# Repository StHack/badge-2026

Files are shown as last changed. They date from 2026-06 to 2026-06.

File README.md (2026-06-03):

# Badge Sthack 2026

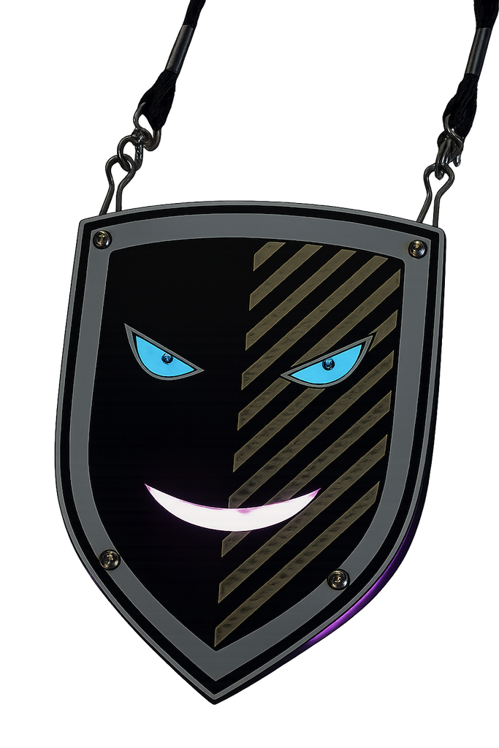
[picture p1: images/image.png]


This electronic badge was designed for [Sthack 2026](https://sthack.fr) and given to every participant at the beginning of the CTF on May 29th, 2026.

| [User manual](firmware/README.md) | [Hardware](hardware/README.md) |
| --- | --- |

---

## Story

The badge was handed to you at the beginning of the CTF, eyes closed, lost in a paradoxical sleep, patiently waiting for the morning to wake up. But the night is long, and full of dreams and nightmares.

**Can you comfort it?**

---

## First boot

The badge starts in **sleep mode**. After powering on (confirmed by a beep), nothing happens. Its eyes are closed.

If you press a button, its eyes open for a brief moment, it sees you, then fall back shut. Nothing else. He's sleeping.

---

## Nightmares

During its sleep, the badge wakes up randomly every **5 to 15 minutes**. When a nightmare strikes:

- Its eyes turn sick and blurry
- It lets out its unique cry
- Its LEDs pulse red

**You have 20 seconds to react.**

Press any button to launch a minigame. Win the game to level up the badge: heart eyes, pink LEDs, a victory jingle, and the level number scrolled across the displays.

Miss the window and the nightmare passes without consequence, it will try again later.

**Reach level 10 to unlock the CTF flag.**

### Minigames

| Level | Game | How to play | Score required |
| ----- | --- | --- | --- |
| 1 | **Stop** | Stop the cursor inside the zone | 3 rounds |
| 2 | **Dino** | Jump over obstacles | 5 obstacles |
| 3 | **Maze** | LEFT/RIGHT to rotate, CENTER to move forward | Reach the exit |
| 4 | **Pac-Man** | Eat dots, avoid ghosts | 20 points |
| 5 | **Snake** | LEFT/RIGHT, eat food without hitting borders or yourself | 10 points |
| 6 | **Tetris** | Clear horizontal lines | 8 lines |
| 7 | **Breakout** | Destroy all bricks (5 lives) | Clear all bricks |
| 8 | **Simon** | Memorise and repeat the button sequence | 8 rounds |
| 9 | **Flappy Bird** | CENTER to flap through the pipes | 10 points |
| 10 | **Mastermind**  | Deduce the hidden sequence | Find the code |

---

## Wake-up

At the end of the night, a wake signal was broadcast to wake all badges simultaneously. Every badge that was still present opened its eyes, lit up its LEDs, played its unique melody.

From that point on, the badge is fully awake: eyes animated at all times, full menu accessible, all minigames unlocked, and customisation available.

Badges that had left the event before the signal remained asleep.

---

## Badge identity

Each badge has its own unique name, cry, and melody.

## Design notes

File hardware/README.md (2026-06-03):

# Hardware

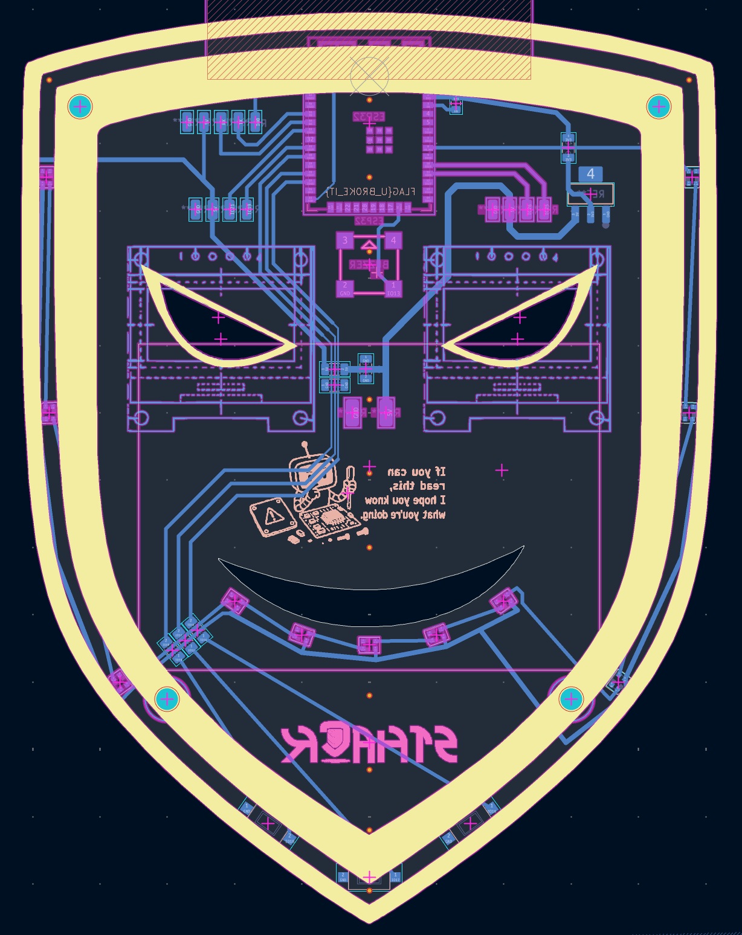
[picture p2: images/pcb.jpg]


## Overview

The entire design, fabrication, assembly, and programming of 200 badges was completed in one month as a side project. With no time to run test batches before the final production run, every decision had to be right the first time. This shaped the approach: minimize risk by keeping the design simple and well-understood, rather than pushing boundaries that could not be validated in time.

---

## PCB

The [KiCad project](pcb/) is a two-layer SMD board shaped like the Sthack shield. All components are mounted on the back. The two OLED displays are soldered using U-shaped pin headers, keeping the front surface completely clean with no visible holes. This was a deliberate aesthetic choice.

---

## 3D printed plate

A 3D printed plate screws onto the back of the PCB and is shaped to fit around the components. It houses several integrated features:

- Small tunnels run behind the mouth LED strip to diffuse the light more evenly across the front.
- Two sliding brackets hold the AA battery box in place.
- A stop piece prevents the battery box from being pulled out too easily.
- The lanyard hooks are sandwiched between the plate and the PCB, held in place by the assembly itself without additional fasteners.

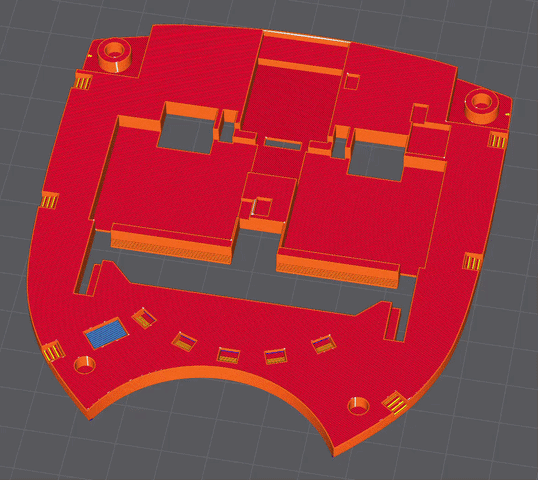
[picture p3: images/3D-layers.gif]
3D layers


---

## Assembly process

### Screen soldering

A printed support and a plate hold both OLED displays at the correct height and angle during soldering, ensuring perfect alignment on every badge.

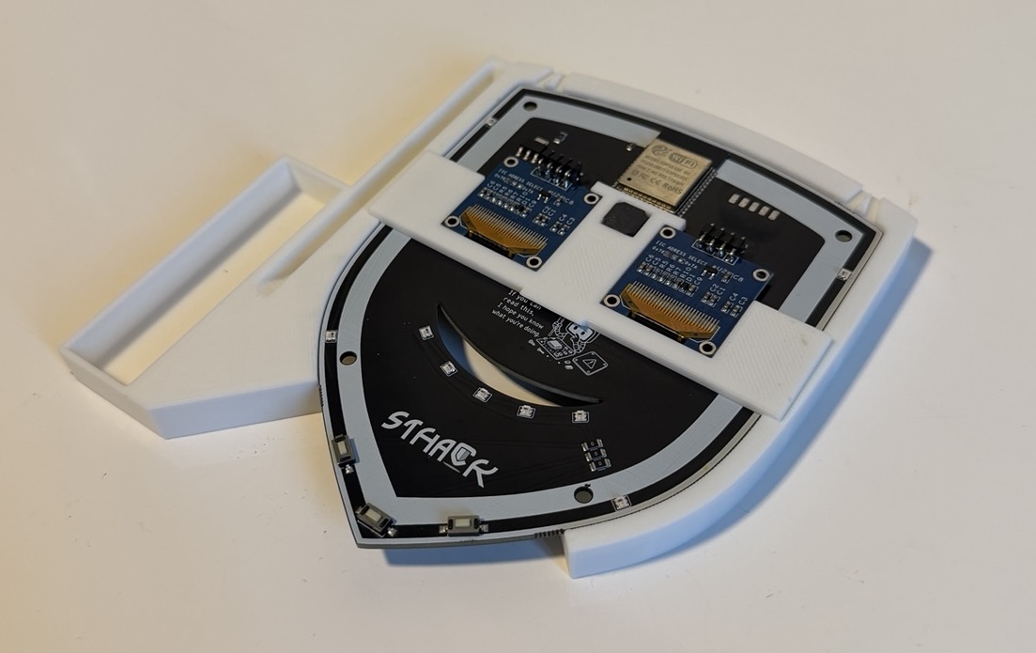
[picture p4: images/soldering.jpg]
Screen soldering


Files are in [`3D/soldering/`](3D/soldering/).

### Programming

Each PCB is placed into a custom-made programming dock that holds the badge at a fixed position, aligning a set of pogo pins with the programming pads on the board. This allows flashing the firmware without soldering any connector.

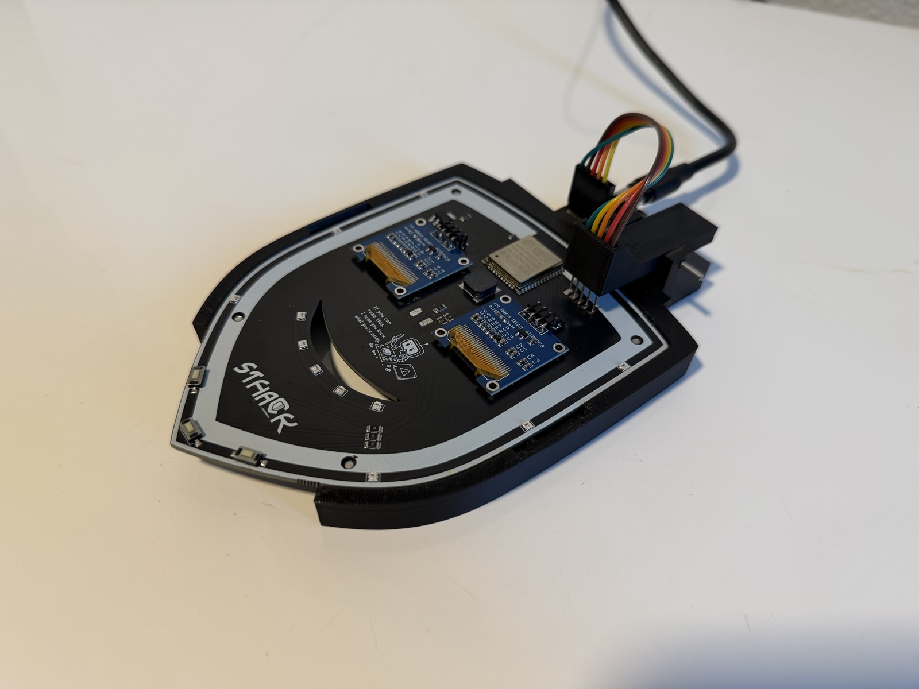
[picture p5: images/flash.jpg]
Programming


The dock is 3D printed. Files are in [`3D/programming/`](3D/programming/).

To speed up flashing 200 badges, a batch script ([`firmware/flash_batch.py`](../firmware/flash_batch.py)) flashes multiple badges in parallel across several USB ports. An audio feedback system plays distinct sounds to signal when a flash succeeds or fails, so there is no need to watch the screen between each badge.

### Brass thread inserts

The 3D plate uses heat-set brass inserts for the screw holes. A jig positions the plate precisely under the soldering iron tip to make insertion consistent.

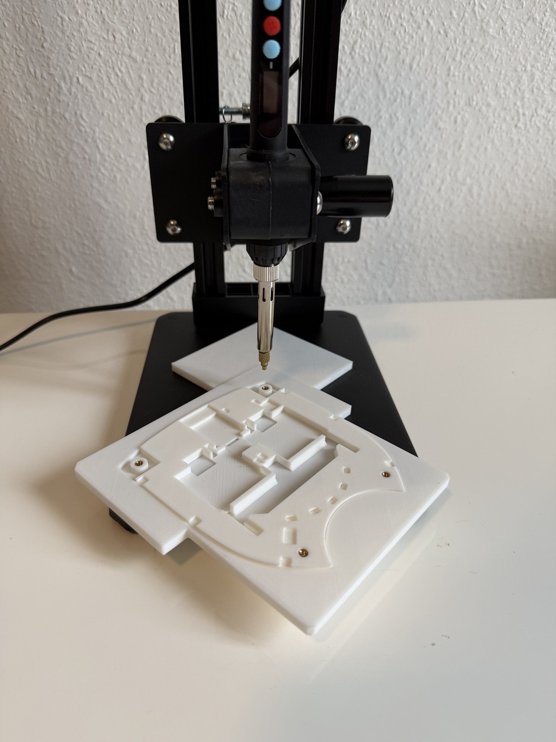
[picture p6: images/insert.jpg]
Thread inserts


Files are in [`3D/threads/`](3D/threads/).

### Final assembly

Components are positioned on the plate, the battery box wires are soldered to the PCB, and everything is secured with 4 screws, also holding necklace.

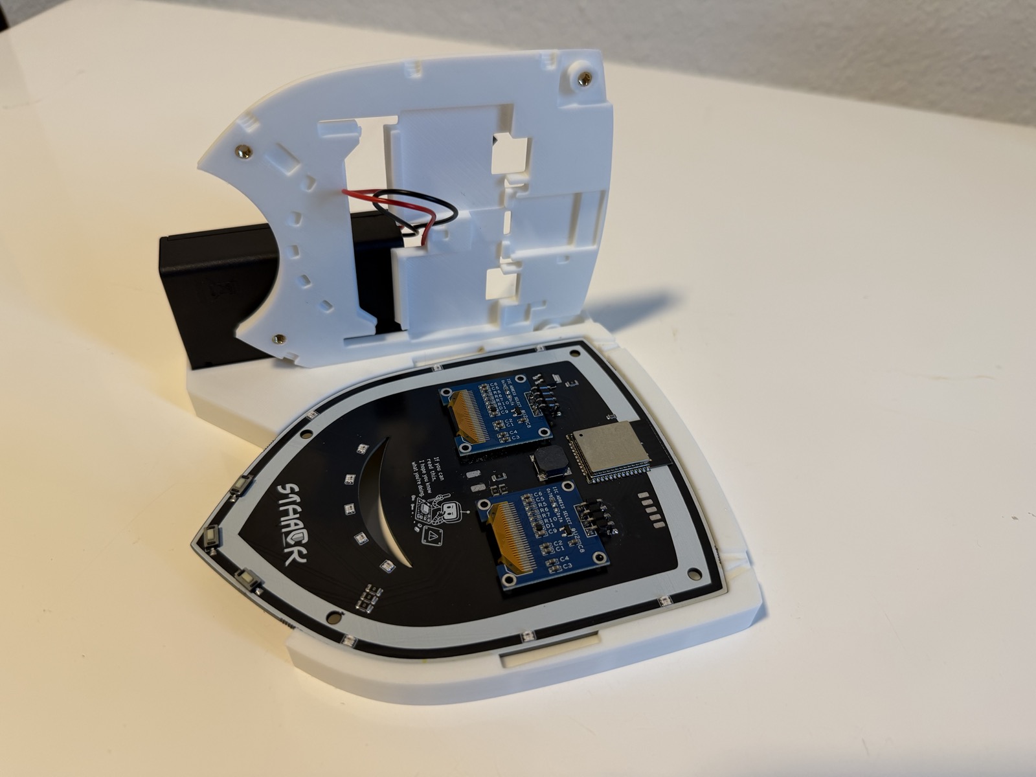
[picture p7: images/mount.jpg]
Final assembly


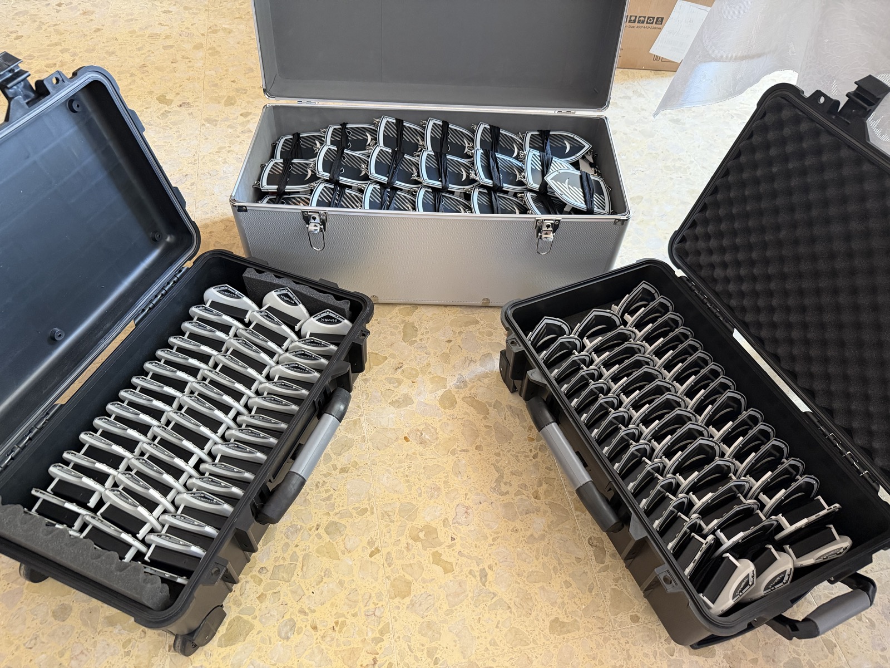
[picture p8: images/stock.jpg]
200 finished badges


---

## Bill of materials

| Component | Reference | Details |
| --- | --- | --- |
| SoC | [ESP32-WROOM-32E](components-datasheets/C19949066.pdf) | 240 MHz, 4 MB Flash, 520 KB SRAM, BLE + WiFi |
| Display | [SSD1306](components-datasheets/SSD1306.jpeg) x 2 | 128x64 OLED, I2C @ 0x3C |
| LEDs | [WS2812B](components-datasheets/C965555.pdf) x 11 | 3 left ring + 5 mouth + 3 right ring, single GPIO data line |
| Buttons | SMD push x 3 | Active-low, internal pull-up, Left / Center / Right |
| Buzzer | [Passive piezo](components-datasheets/C7544813.pdf) | PWM via LEDC, ~2500 Hz resonance |
| Regulator | [AMS1117-3.3](components-datasheets/C6186.pdf) | 3.3 V LDO regulator for the ESP32 |
| Resistors | [0402](components-datasheets/C17888.pdf) | Pull-up / current-limiting resistors |

---

## Pin assignments

| Signal | GPIO |
| --- | ---- |
| Left display SDA  | 19 |
| Left display SCL  | 21 |
| Right display SDA | 25 |
| Right display SCL | 26 |
| WS2812B data | 32 |
| Button LEFT | 18 |
| Button CENTER | 17 |
| Button RIGHT | 16 |
| Buzzer PWM | 13 |

---

## LED segments

The 11 LEDs are wired in a single chain on GPIO 32:

```
Index  0  1  2        Left ring  (3 LEDs)
Index  3  4  5  6  7  Mouth strip (5 LEDs)
Index  8  9  10       Right ring (3 LEDs)
```

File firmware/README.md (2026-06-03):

# User Guide

## Menu

Hold **CENTER** for 0.5 s in awake mode to open the menu.

```
Menu
├── Info
│   ├── Name
│   ├── ID
│   └── Version
├── Games
│   └── [Games list]
├── Skin
│   ├── Eyes
│   ├── Mouth
│   ├── Rings
│   └── Blink
├── Settings
│   ├── LEDs
│   ├── Sound
│   └── Bluetooth
│       ├── Server
│       └── Remote control
└── Bonus
```

- **Navigate:** LEFT / RIGHT to browse entries
- **Confirm:** CENTER (short press)
- **Back / exit:** hold CENTER

### Info

Displays your badge's identity:

- **Name:** your badge's unique name (plays its unique cry when clicked)
- **ID:** its 6-character identifier
- **Version:** firmware version

### Games

Play any game freely, without waiting for a nightmare. The first 10 are part of the tamagotchi progression.

| Game | How to play |
| --- | --- |
| **Simon** | Memorise and repeat the button sequence |
| **Stop** | Stop the cursor inside the zone |
| **Snake** | Eat food without hitting borders or yourself |
| **Mastermind**  | Deduce the hidden sequence |
| **Tetris** | Clear horizontal lines |
| **Flappy Bird** | CENTER to flap through the pipes |
| **Breakout** | Destroy all bricks without letting the ball fall |
| **Pac-Man** | Eat dots, avoid ghosts |
| **Doodle Jump** | Keep jumping upward without falling |
| **Maze** | LEFT/RIGHT to rotate, CENTER to move forward |
| **Dino** | Jump over obstacles |
| **Space Inv.**  | Shoot down waves of descending aliens |

### Skin

Customise the visual appearance of your badge.

| Option | Available styles |
| --- | --- |
| **Eyes**  | Standard, Hearts, Stars, Matrix, Hypnosis, Bolt, Reptile, Infinity, Anime, Scope, Clock, Robot, Lock, Wifi, Cat, Human |
| **Mouth** | Off, Pink, Rainbow, Lava, Chill, Candle, Cyber, VU, Bounce, Sparkle, Ocean, Toxic, Aurora, Heartbeat, Matrix |
| **Rings** | Off, BluePulse, CyanPulse, Rainbow, Fire, Police, Comet, Breathing, Disco, Strobe, GreenPulse, Aurora, Sunset, Thunder, Heartbeat |
| **Blink** | ON / OFF : enable or disable automatic eye blinking |

### Settings

| Setting | What it does |
| --- | --- |
| **LEDs** | Overall LED brightness, from 0 (off) to 10 (maximum) |
| **Sound** | Mute or unmute the buzzer (ON / OFF) |
| **Bluetooth** | Submenu for wireless connection options |
| &emsp;Server | Enable the GATT server to accept Bluetooth connections  |
| &emsp;Remote control | Allow the badge to receive remote BLE commands |

---

## Bluetooth interface

When the GATT server is enabled (Settings > Bluetooth > Server), the badge can be controlled from a browser using the [`badge.html`](badge.html) page.

Open the file locally in Chrome or Edge (Web Bluetooth is not supported in other browsers), click **Connect**, and select your badge from the device list. A PIN is displayed on the badge for a few seconds to confirm the pairing.

During the event, a BLE broadcast system was used to send commands to all badges simultaneously. This can be disabled in Settings > Bluetooth > Remote control. See [`BLUETOOTH.md`](BLUETOOTH.md) for details.

---

## Power

In sleep mode the badge wakes every 30 seconds, scans BLE beacons for 2 seconds, then goes back to sleep. This keeps average current around **17 mA**, giving a comfortable runtime on 3 AA batteries across a full night event. When fully awake (displays on, LEDs animating), consumption rises to around **150 mA**.

---

## Development

### Build

The firmware uses [PlatformIO](https://platformio.org/). From the `firmware/` directory:

```bash
pio run
```

The compiled binary is written to `.pio/build/esp32dev/firmware.bin`.

### Flash over Bluetooth

1. Enable the GATT server on the badge (Settings > Bluetooth > Server).
2. Open `tools/badge.html` in Chrome or Edge and connect to the badge.
3. In the OTA section, drag and drop `firmware.bin` onto the upload area and confirm.

The badge reboots automatically once the transfer is complete.

### Flash via USB

Connect the badge to USB and run:

```bash
pio run --target upload
```

For serial output:

```bash
pio device monitor
```

### Rollback

The flash is split into two OTA slots (see [`partitions_badge.csv`](partitions_badge.csv)):

```
app0  ota_0  0x010000  ~1.97 MB
app1  ota_1  0x200000  ~1.97 MB
```

Each OTA update writes to the inactive slot and switches the boot pointer to it. The previously running firmware stays intact in the other slot.

To roll back to the previous firmware, hold **LEFT + CENTER + RIGHT** while powering on the badge. The bootloader switches the active slot back and reboots into the older firmware.

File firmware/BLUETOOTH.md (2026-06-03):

# Bluetooth signals

Two independent BLE mechanisms coexist: **beacon broadcast** (one-way, no pairing) and **GATT server** (bidirectional, requires pairing).

---

## Beacon format

Signals are broadcast as BLE advertisements with manufacturer-specific data in plain ASCII:

```
ST:<COMMAND>[:<BADGE_ID>][|<PAYLOAD>][~P][~B]
```

| Field | Description |
|---|---|
| `ST:` | Fixed prefix, identifies a Sthack badge signal |
| `<COMMAND>` | Command name (see table below) |
| `:<BADGE_ID>` | Optional, 6-char uppercase hex (last 3 bytes of MAC). If absent, signal applies to all badges |
| `\|<PAYLOAD>` | Optional command-specific data |
| `~P` | Proximity flag, badge ignores this signal if RSSI < -65 dBm |
| `~B` | Boot flag, only processed during the targeted boot scan (hold CENTER at power-on) |

Flags can be combined: `ST:WAKE:A3F201~P~B`

---

## Beacon commands

| Command | Full format | Effect |
|---|---|---|
| `WAKE` | `ST:WAKE[:<ID>]` | Switch badge to **FullMode** (eyes open, menu accessible) |
| `SLEEP` | `ST:SLEEP[:<ID>]` | Return badge to **SleepMode** |
| `BG_ON` | `ST:BG_ON[:<ID>]` | Badge stays awake and scans continuously, ignores sleep timer |
| `BG_OFF` | `ST:BG_OFF[:<ID>]` | Resume normal sleep cycle |
| `CRY` | `ST:CRY[:<ID>]` | Play the badge's unique Pokemon-style cry |
| `MSG` | `ST:MSG[:<ID>]\|<text>` | Cry + scroll text across both displays |
| `OTA` | `ST:OTA[:<ID>]\|<version>` | Connect to the hardcoded WiFi AP and update firmware if badge version < target |
| `TAMA` | `ST:TAMA[:<ID>]` | Force-trigger a tamagotchi interaction immediately |
| `CLEAR` | `ST:CLEAR[:<ID>]` | Reset dedup state, allows re-sending the last command |

### Examples

```
ST:WAKE                        # wake all badges
ST:WAKE:A3F201                 # wake only badge A3F201
ST:MSG|Welcome to Sthack!      # broadcast message to all
ST:MSG:A3F201|Good luck        # targeted message
ST:OTA|0.6                     # OTA update if badge is older than 0.6
ST:TAMA~P                      # trigger tama only for nearby badges (RSSI >= -65 dBm)
ST:WAKE~B                      # only processed during targeted boot scan
```

---

## Deduplication

The badge ignores repeated identical beacons to avoid acting on the same signal multiple times during a scan window. Send `ST:CLEAR` (or `ST:CLEAR:<ID>`) to reset this state before re-sending a command.

---

## GATT server

The GATT server is started from **Settings > Bluetooth** in FullMode. It requires a PIN confirmation on the badge before accepting commands (4-digit PIN displayed on screen, enter via buttons).

**Service UUID:** `19b10020-e8f2-537e-4f6c-d104768a1214`

| Characteristic | UUID | Access | Purpose |
|---|---|---|---|
| Info | `19b10021-...` | Read | Badge ID, name, firmware version |
| Command | `19b10023-...` | Write | Control commands (see below) |
| Music | `19b10024-...` | Write | Play RTTTL melody |
| PIN | `19b10025-...` | Write | Submit PIN for authentication |
| OTA data | `19b10027-...` | Write | BLE OTA firmware transfer (244-byte chunks) |

### GATT command strings (write to `19b10023`)

| Command | Effect |
|---|---|
| `EYE:<N>` | Set eye animation (0=FSM, 1=closed, 2=awake, 3=sleepy, 4=hearts, 5=scroll, 6=blinking, 7=calm) |
| `LED:<N>` | Set LED animation mode |
| `TEXT:<text>` | Scroll text across both displays |
| `MUSIC:<rtttl>` | Play an RTTTL melody |
| `CRY` | Trigger badge cry |
| `STYLE:<N>` | Set eye style |
| `GAME:<N>` | Launch a minigame (0=Simon, 1=Stop, 2=Snake, 3=Mastermind, 4=Tetris, 5=Flappy, 6=Breakout, 7=Pac-Man, 8=Doodle, 9=Maze) |
| `TAMA_TRIGGER` | Force tamagotchi interaction |
| `NVS_RESET` | Erase all NVS data and reboot (factory reset) |
| `FSM_WAKE` | Switch to FullMode |
| `FSM_SLEEP` | Switch to SleepMode |

---

## Proximity gating (`~P`)

Any beacon can be restricted to nearby badges by appending `~P`. The badge measures the RSSI of the advertisement and ignores it if RSSI < -65 dBm (approximately 1-2 m in open space). Adjust `kProximityRssiThreshold` in `src/ble/ble_types.h` to tune the range.

---

## Boot-time targeted scan (`~B`)

If CENTER is held at power-on, the badge enters a 2-second targeted scan that only reacts to `~B`-flagged beacons. This allows an organiser to send a command to a specific badge without triggering all nearby badges. Normal broadcast beacons are ignored during this window.

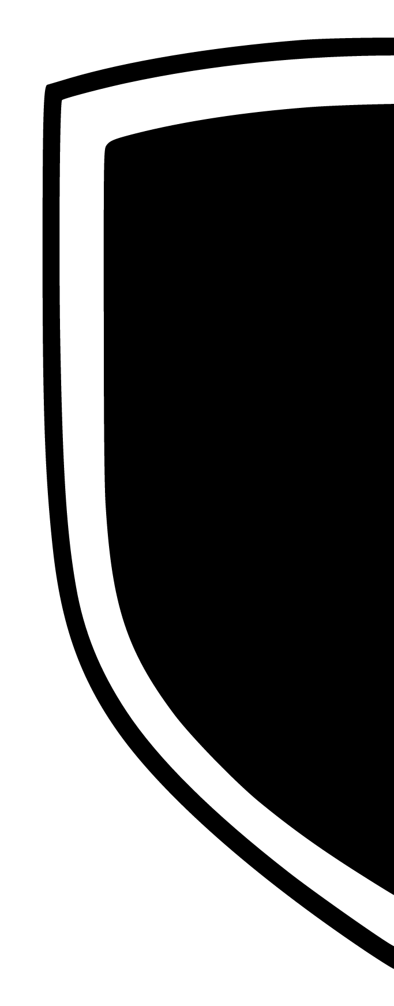
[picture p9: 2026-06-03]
hardware/images/shield/half-shield-left.png

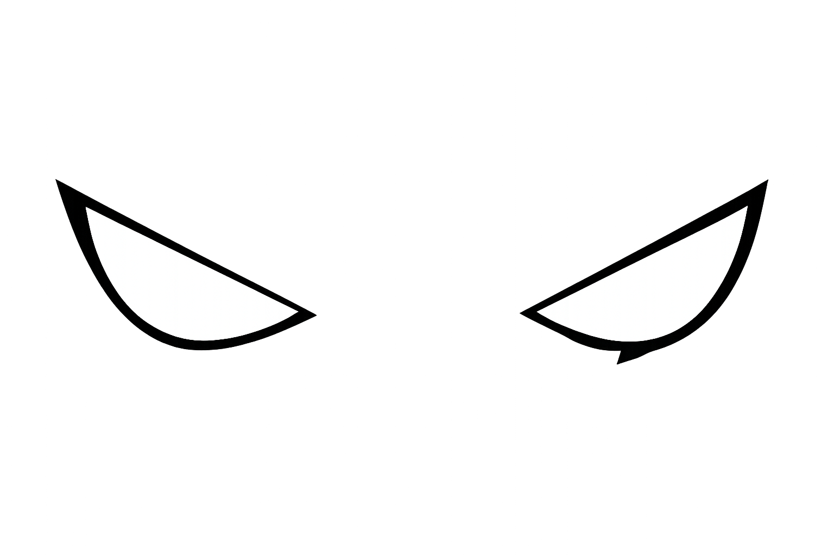
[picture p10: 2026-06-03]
hardware/images/face/eyes-source.png

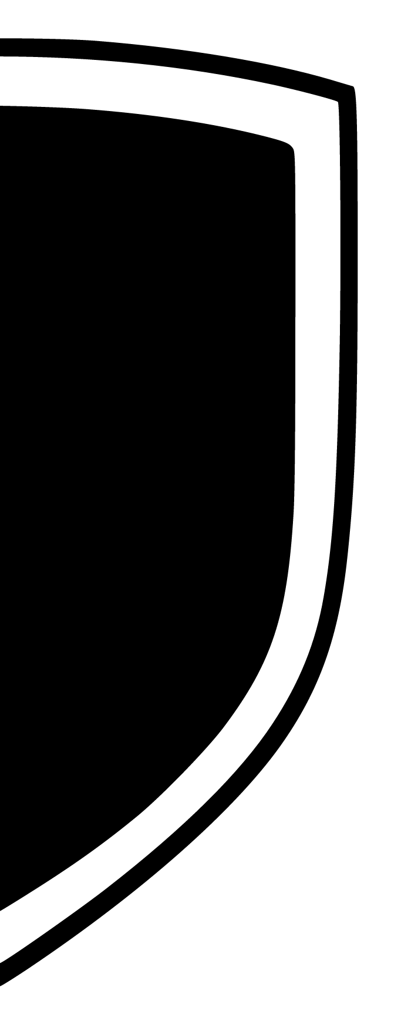
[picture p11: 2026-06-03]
hardware/images/shield/half-shield-right.png

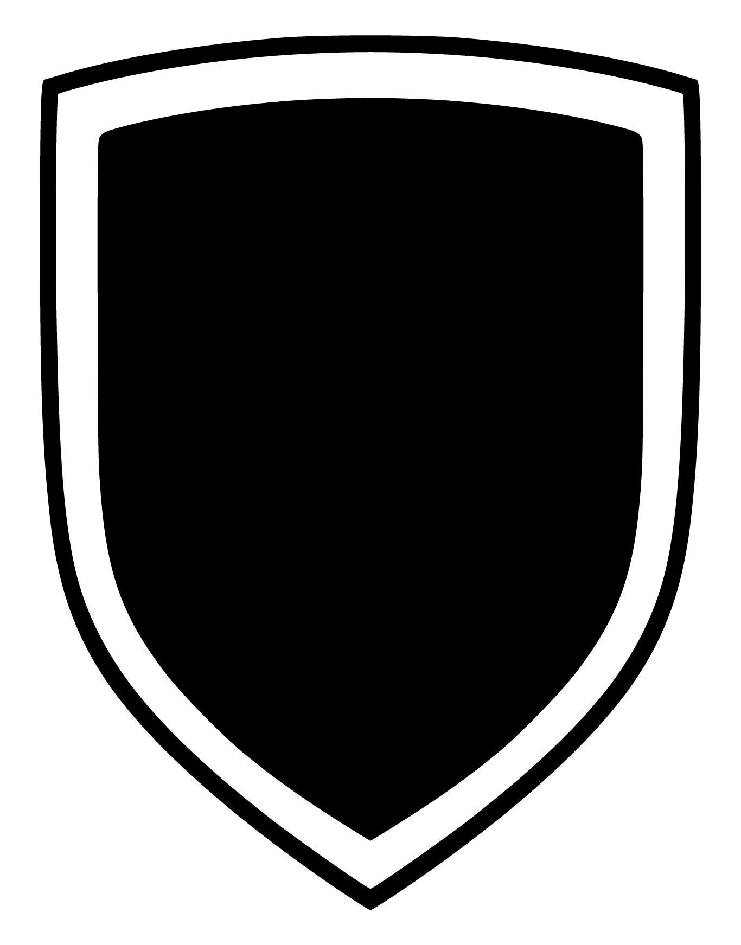
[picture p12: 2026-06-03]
hardware/images/shield/mirror-shield.png

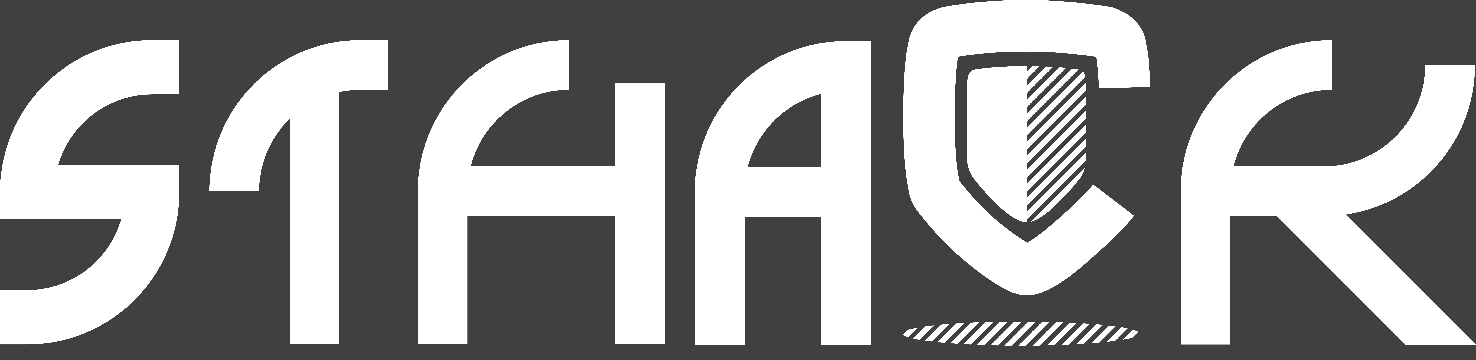
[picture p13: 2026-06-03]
hardware/images/sthack.png

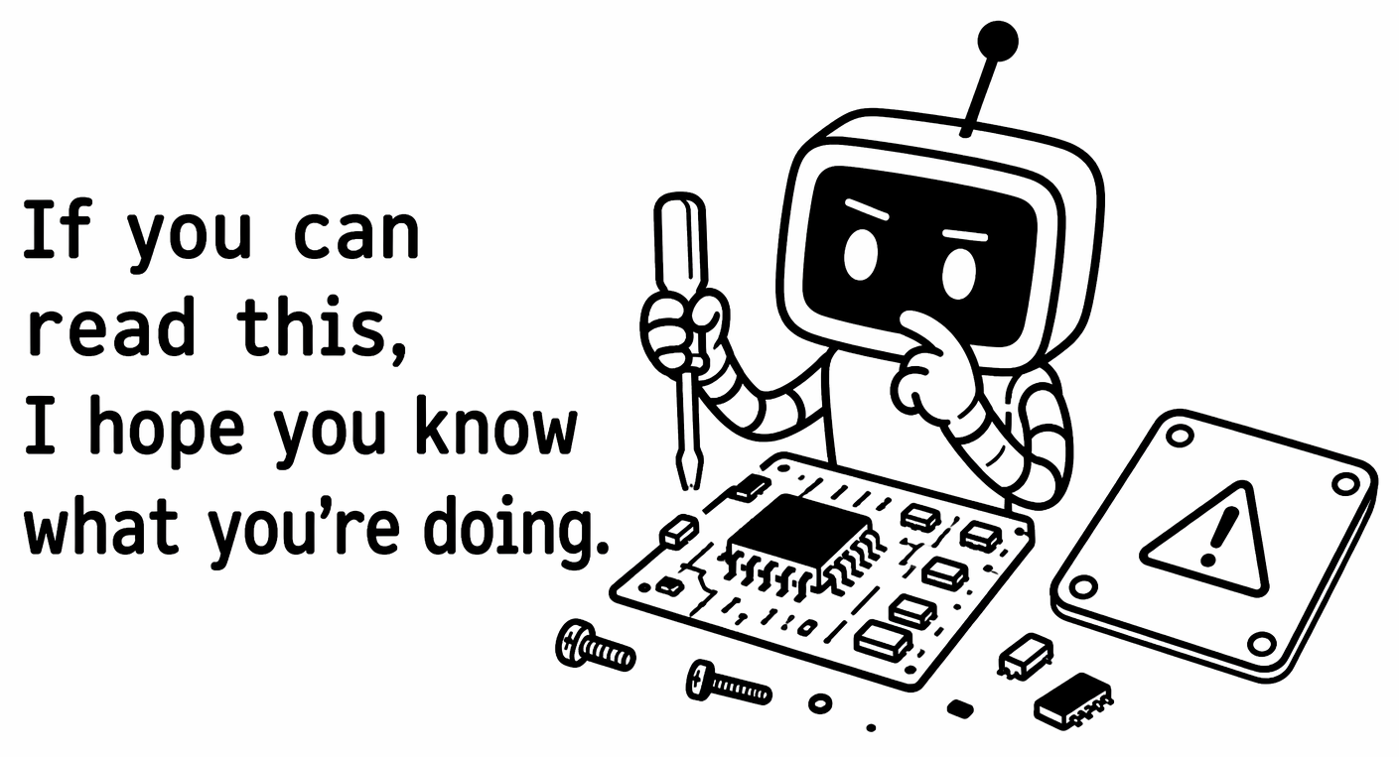
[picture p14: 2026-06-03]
hardware/images/joke.png

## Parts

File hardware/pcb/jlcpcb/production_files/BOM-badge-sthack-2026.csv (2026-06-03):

Comment | Designator | Footprint | LCSC | Quantity
 | BRG | R_1206_3216Metric | C17888 | 1
AMS | AMS | SOT-223-3_L6.5-W3.4-P2.30-LS7.0-BR | C6186 | 1
BUZZER | BUZZER | BUZ-SMD_4P-L8.5-W8.5-P8.50-BR | C7544813 | 1
EN | EN | R_0805_2012Metric | C17414 | 1
ESP32 | ESP32 | ESP32-WROOM-32E | C19949066 | 1
LED_WS2812B-2020_PLCC4_2.0x2.0mm | LED | LED_WS2812B-2020_PLCC4_2.0x2.0mm | C965555 | 1
SW_SPST_CK_RS282G05A3 | BTN | SW_SPST_CK_RS282G05A3 | C2681478 | 1

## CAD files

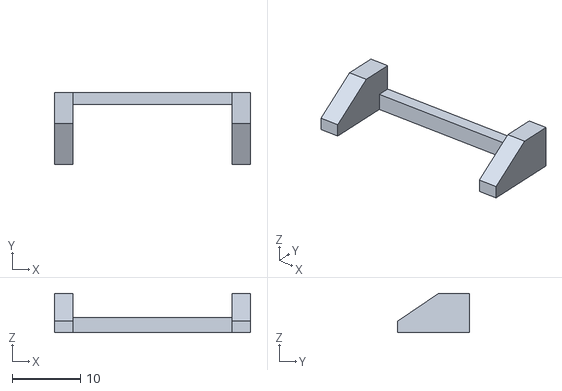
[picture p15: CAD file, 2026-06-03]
hardware/3D/badge/badge-batteries-stop.stl
28.8 x 10.5 x 5.75

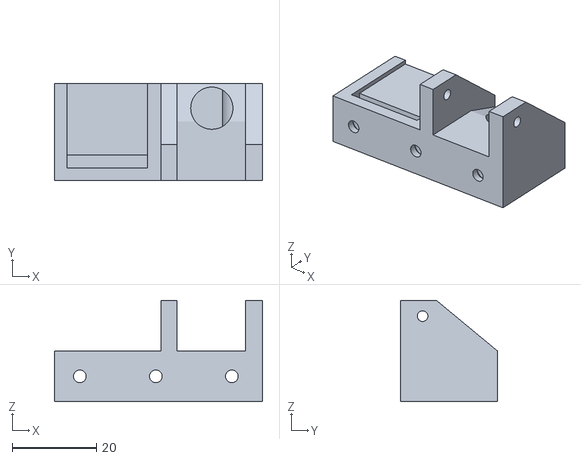
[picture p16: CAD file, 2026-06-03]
hardware/3D/programming/programming-tool-lever-support.stl
49.2 x 23.0 x 24.0

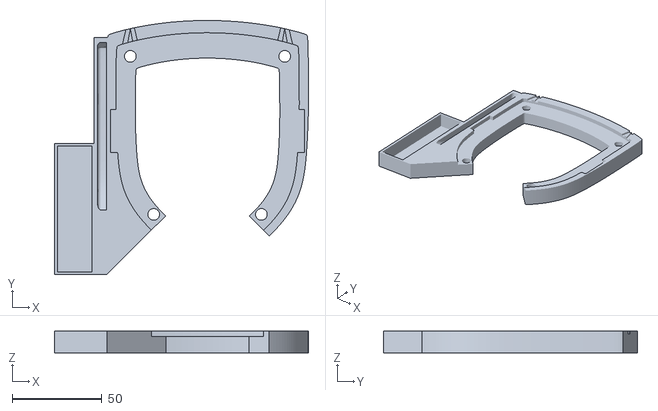
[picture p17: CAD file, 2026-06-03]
hardware/3D/soldering/soldering-support.stl
141.5 x 141.5 x 12.0

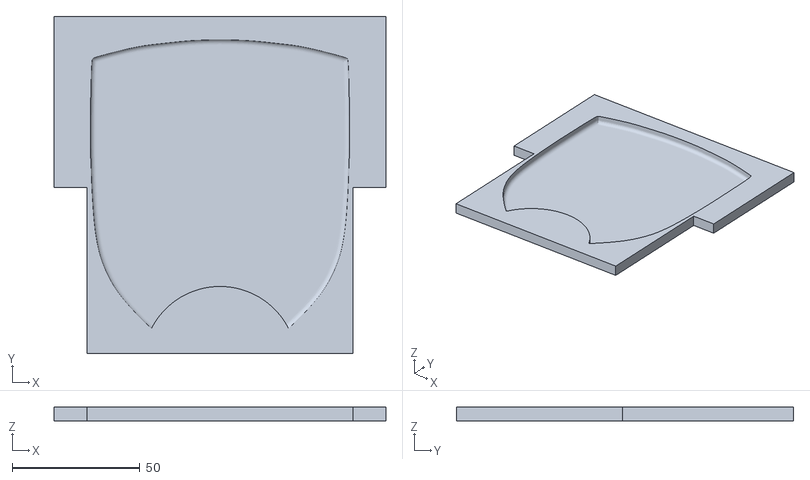
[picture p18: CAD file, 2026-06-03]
hardware/3D/threads/brass-threads-tool-support.stl
130.1 x 132.1 x 5.50

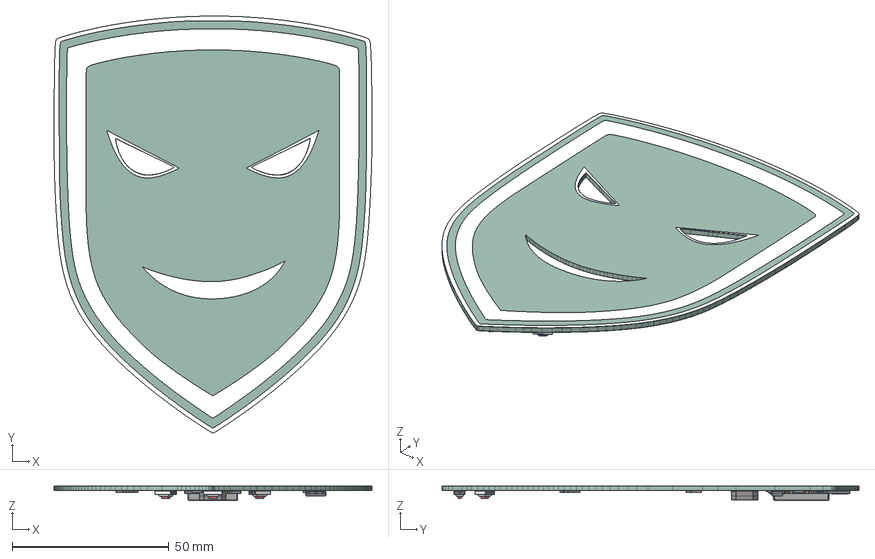
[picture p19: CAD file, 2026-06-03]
hardware/pcb/badge.step
101.6 x 133.2 x 4.77 mm
ESP32-WROOM-32E
R_0805_2012Metric
SOT-223-3_L6.5-W3.4-P2.30-LS7.0-BR
R_1206_3216Metric x 7
SW_SPST_CK_RS282G05A3 x 3
BUZ-SMD_4P-L8.5-W8.5-H3.0
badge-sthack-2026_silkscreen x 2
badge-sthack-2026_PCB

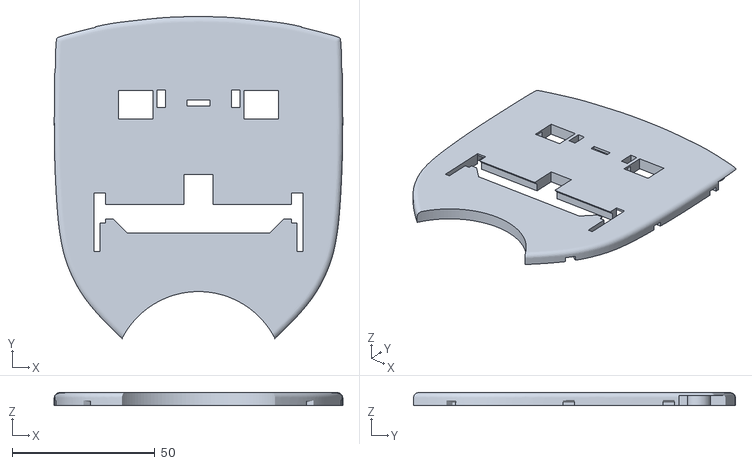
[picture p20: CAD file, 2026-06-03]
hardware/3D/badge/badge-plate.stl
101.0 x 112.7 x 4.50

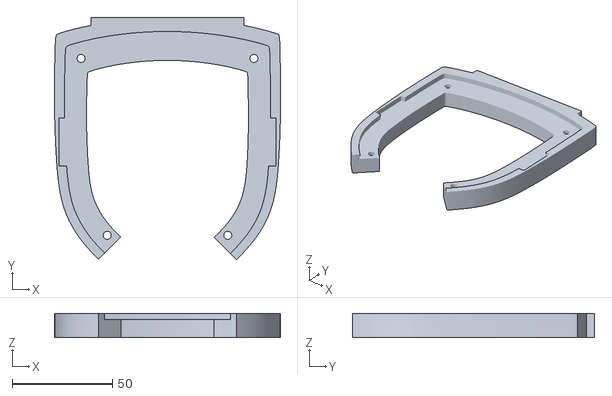
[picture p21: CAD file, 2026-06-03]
hardware/3D/programming/programming-tool.stl
112.5 x 120.6 x 12.0

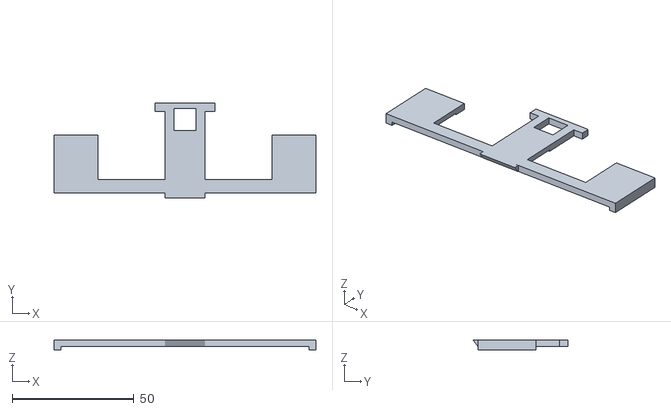
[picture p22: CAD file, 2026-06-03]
hardware/3D/soldering/soldering-screens-support.stl
107.8 x 39.0 x 4.00

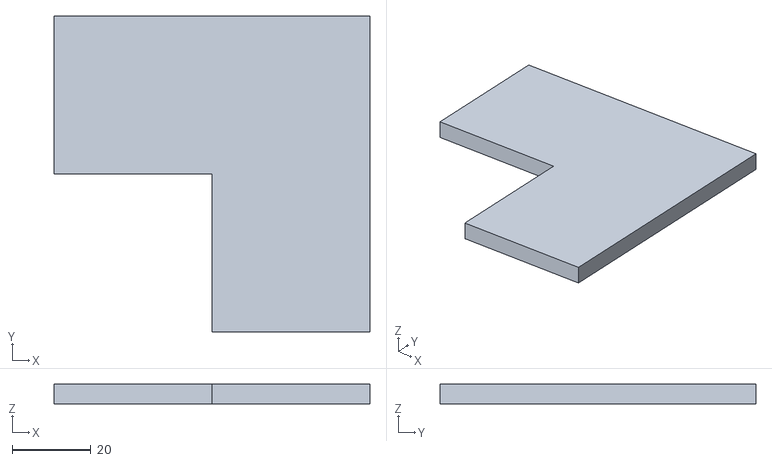
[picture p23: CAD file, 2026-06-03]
hardware/3D/threads/brass-threads-tool-support-positionning.stl
80.0 x 80.0 x 5.00

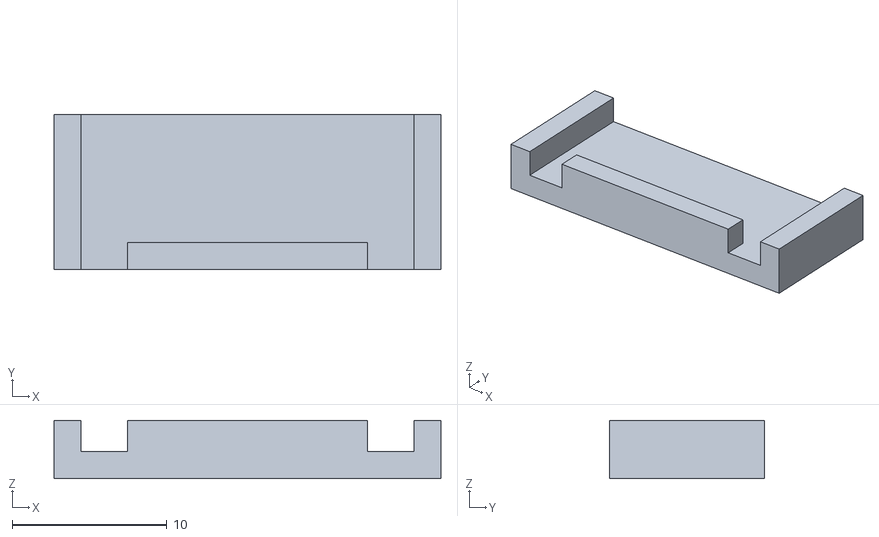
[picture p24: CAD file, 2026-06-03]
hardware/3D/badge/badge-batteries-support.stl
25.0 x 10.0 x 3.75

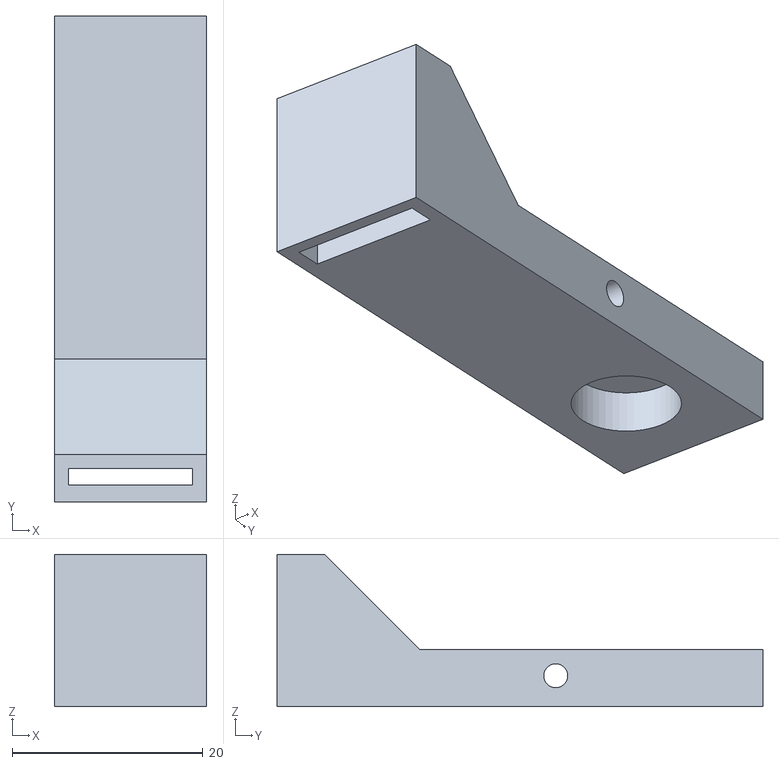
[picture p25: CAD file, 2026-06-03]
hardware/3D/programming/programming-tool-lever.stl
16.0 x 51.0 x 16.0

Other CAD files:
hardware/pcb/badge.stl

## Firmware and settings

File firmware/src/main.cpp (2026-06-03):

/* Badge Sthack 2026 — Firmware v1.0 */

#include <Arduino.h>
#include <esp_ota_ops.h>

#include "config/hardware.h"
#include "config/timing.h"
#include "config/version.h"

#include "hal/buttons.h"
#include "hal/buzzer.h"
#include "hal/display.h"
#include "hal/leds.h"

#include "core/identity.h"

#include "sleep/power.h"
#include "sound/rtttl.h"
#include "sound/cry.h"

#include "eyes/eye_calibration.h"
#include "eyes/eye_catalog.h"
#include "eyes/eye_renderer.h"
#include "eyes/eye_animation.h"

#include "leds/led_anim.h"
#include "leds/led_anim_zones.h"

#include "ble/gatt_server.h"
#include "ble/ble_ota.h"
#include "wifi_ota/ota.h"

#include "games/simon_game.h"
#include "games/stop_game.h"
#include "games/snake_game.h"
#include "games/mastermind_game.h"
#include "games/tetris_game.h"
#include "games/flappy_game.h"
#include "games/breakout_game.h"
#include "games/pacman_game.h"
#include "games/doodle_game.h"
#include "games/maze_game.h"
#include "games/dino_game.h"
#include "games/space_game.h"
#include "games/minigame_ui.h"

#include "tamagotchi/tamagotchi.h"

#include "mode_sleep/badge_fsm.h"
#include "mode_full/badge_menu.h"

// ── Frame pacing ──────────────────────────────────────────────────────────────
// Poll buttons at 1 ms resolution so short presses are never missed.
static void waitNextFrame() {
    // Clear latched presses from the current frame before accumulating new ones.
    // This ensures gButtonPressedLatched[i] reflects presses that happen *between*
    // frames (during this delay window) rather than the press that opened the frame.
    buttonsClearLatched();
    uint32_t start = millis();
    while (millis() - start < kFrameMs) {
        pollButtons();
        delay(1);
    }
}

// ── Rollback check ────────────────────────────────────────────────────────────
// If all 3 buttons are held at power-on, switch to the inactive OTA partition
// and reboot. This lets the user recover from a bad firmware update.
static void checkRollback() {
    // Raw GPIO read — buttonsInit() has not run yet.
    pinMode(kPinBtnLeft,   INPUT_PULLUP);
    pinMode(kPinBtnCenter, INPUT_PULLUP);
    pinMode(kPinBtnRight,  INPUT_PULLUP);
    delay(50);  // let pins settle

    if (digitalRead(kPinBtnLeft)   != LOW ||
        digitalRead(kPinBtnCenter) != LOW ||
        digitalRead(kPinBtnRight)  != LOW) {
        return;
    }

    Serial.println("[rollback] all buttons held — checking alternate partition");

    const esp_partition_t* running = esp_ota_get_running_partition();
    const esp_partition_t* target  = esp_ota_get_next_update_partition(NULL);

    if (!target) {
        Serial.println("[rollback] no alternate partition");
        return;
    }

    esp_app_desc_t desc;
    if (esp_ota_get_partition_description(target, &desc) != ESP_OK) {
        Serial.println("[rollback] alternate partition has no valid app");
        return;
    }

    Serial.printf("[rollback] %s -> %s  fw=%s\n",
                  running->label, target->label, desc.version);

    // Show feedback on both displays before rebooting.
    displayInit(gLeftDisplay,  gLeftBus,  kPinLeftSda,  kPinLeftScl,  "left");
    displayInit(gRightDisplay, gRightBus, kPinRightSda, kPinRightScl, "right");
    for (Adafruit_SSD1306* d : {&gLeftDisplay, &gRightDisplay}) {
        d->clearDisplay();
        d->setTextSize(1);
        d->setTextColor(SSD1306_WHITE);
        d->setCursor(20, 18);
        d->print("Rollback...");
        d->setCursor(4, 34);
        d->print(target->label);
        d->print("  ");
        d->print(desc.version);
        d->display();
    }
    delay(1500);

    esp_ota_set_boot_partition(target);
    esp_restart();
}

// ── Arduino setup ─────────────────────────────────────────────────────────────
void setup() {
    Serial.begin(115200);
    delay(100);

    // Read buttons early — raw GPIO, before any init that could disrupt state.
    // Must come first so the user only needs to hold buttons during power-on,
    // not through the entire init sequence.
    pinMode(kPinBtnLeft,   INPUT_PULLUP);
    pinMode(kPinBtnCenter, INPUT_PULLUP);
    pinMode(kPinBtnRight,  INPUT_PULLUP);
    delay(10);
    const bool centerHeldAtBoot = (digitalRead(kPinBtnCenter) == LOW);
    const bool secretWakeAtBoot = (digitalRead(kPinBtnLeft)   == LOW)
                                && (digitalRead(kPinBtnRight)  == LOW)
                                && (digitalRead(kPinBtnCenter) != LOW);

    // Rollback: must run before any other init.
    checkRollback();

    // Badge identity (must come first — other modules use it)
    badgeIdInit();
    Serial.printf("[boot] fw=%s id=%s name=%s\n",
                  firmwareVersionString(), badgeIdHexString(), badgeIdName());

    // Hardware
    buttonsInit();
    buzzerInit();
    ledsInit();
    displayInit(gLeftDisplay,  gLeftBus,  kPinLeftSda,  kPinLeftScl,  "left");
    displayInit(gRightDisplay, gRightBus, kPinRightSda, kPinRightScl, "right");

    // Persistent state
    eyeCalLoad();
    eyeCatalogStyleLoad();
    tamaInit();
    ledZonesLoad();
    badgeMenuSettingsLoad();

    // Badge FSM
    badgeFsmInit();

    // Restore GATT server if it was active before last reboot (FullMode only).
    if (gGattPersisted && gBadgeMode == BadgeMode::FullMode) {
        Serial.println("[boot] restoring GATT server (persisted)");
        badgeFsmSignalGattOn();
    }

    if (secretWakeAtBoot) {
        Serial.println("[boot] secret wake — awaiting code (sliding window)");
        static constexpr uint8_t kSecretLen = 6;
        static constexpr uint8_t kSecret[kSecretLen] = {0, 0, 2, 1, 2, 0};
        uint8_t buf[kSecretLen] = {};
        uint8_t count = 0;
        bool    found = false;
        while (!found) {
            pollButtons();
            for (uint8_t i = 0; i < 3; i++) {
                if (gButtonPressedLatched[i]) {
                    buttonsClearLatched();
                    // Slide buffer left, append new press
                    for (uint8_t j = 0; j < kSecretLen - 1; j++) buf[j] = buf[j + 1];
                    buf[kSecretLen - 1] = i;
                    if (++count >= kSecretLen) {
                        found = true;
                        for (uint8_t j = 0; j < kSecretLen; j++) {
                            if (buf[j] != kSecret[j]) { found = false; break; }
                        }
                    }
                    break;
                }
            }
            delay(1);
        }
        Serial.println("[boot] secret code OK — FullMode");
        badgeFsmSignalWake();
    }

    // Boot acknowledgement beep
    buzzerBeep(kBootBeepHz, kBootBeepMs);
    Serial.printf("[boot] sleep_interval=%us scan_window=%ums\n",
                  kSleepIntervalSec, kBeaconScanMs);

    // Targeted boot scan: if CENTER is held at boot, scan exclusively for ~B beacons.
    // This allows an organiser to push a targeted command to a specific badge
    // without it being triggered by a nearby broadcast.
    Serial.printf("[boot] centerHeldAtBoot=%d\n", centerHeldAtBoot);
    if (centerHeldAtBoot) {
        Serial.println("[boot] CENTER held — targeted boot scan mode");
        badgeFsmTargetedBootScan();
    }

    // First sleep — scan only if CENTER was held (targeted boot scan already ran above).
    // On a plain cold boot, go directly to sleep without scanning.
    badgeFsmHandleSleepEntry(centerHeldAtBoot);
}

// ── Arduino loop ──────────────────────────────────────────────────────────────
void loop() {
    pollButtons();
    const uint32_t now = millis();

    // ── GATT tick first: handles auth UI and button events for PIN confirm ─
    gattTick(now);
    static bool sPrevAuthPending = false;
    if (gattAuthPending()) {
        sPrevAuthPending = true;
        waitNextFrame();
        return;
    }
    if (sPrevAuthPending) {
        // Auth just ended — absorb any button presses so menu/games don't react
        sPrevAuthPending = false;
        badgeMenuSyncButtons();
        buttonsClearLatched();
        return;
    }

    // ── ① OTA binary transfer: tight loop, nothing else runs ──────────────
    if (bleOtaInProgress()) {
        bleOtaTick(now);
        delay(8);
        return;
    }
    if (otaTransferActive()) {
        otaTick();
        pollButtons();
        delay(3);
        return;
    }

    // ── ② Badge menu (FullMode only) ──────────────────────────────────────
    if (gBadgeMode == BadgeMode::FullMode) {
        badgeMenuTick(now);
        if (badgeMenuIsOpen()) {
            badgeFsmTick(now);
            if (badgeFsmMsgActive()) {
                displaysOn();
                eyesDrawBoth(badgeFsmComputePose(now), badgeFsmComputeExpression(now), badgeFsmScrollText(now));
            }
            ledAnimTick(now);
            rtttlTick(now);
            cryTick(now);
            waitNextFrame();
            return;
        }
    }

    // ── ④ Minigames ────────────────────────────────────────────────────────
#define GAME_TICK(active, tick) \
    if (active()) { \
        badgeFsmTick(now); \
        if (badgeFsmMsgActive()) { \
            displaysOn(); \
            eyesDrawBoth(badgeFsmComputePose(now), badgeFsmComputeExpression(now), badgeFsmScrollText(now)); \
        } else { \
            tick(now); minigameUiPaintTourFlashIfActive(now); \
        } \
        rtttlTick(now); cryTick(now); waitNextFrame(); return; \
    }

    GAME_TICK(simonGameIsActive,     simonGameTick)
    GAME_TICK(stopGameIsActive,      stopGameTick)
    GAME_TICK(snakeGameIsActive,     snakeGameTick)
    GAME_TICK(mastermindGameIsActive, mastermindGameTick)
    GAME_TICK(tetrisGameIsActive,    tetrisGameTick)
    GAME_TICK(flappyGameIsActive,    flappyGameTick)
    GAME_TICK(breakoutGameIsActive,  breakoutGameTick)
    GAME_TICK(pacmanGameIsActive,    pacmanGameTick)
    GAME_TICK(doodleGameIsActive,    doodleGameTick)
    GAME_TICK(mazeGameIsActive,        mazeGameTick)
    GAME_TICK(dinoGameIsActive,        dinoGameTick)
    GAME_TICK(spaceGameIsActive,       spaceGameTick)
#undef GAME_TICK

    // ── ⑤ Badge FSM tick (BLE signals, stage transitions) ─────────────────
    badgeFsmTick(now);

    // ── ⑥ Tamagotchi: drive interaction, forward buttons ──────────────────
    bool tamaActive = tamaTick(now);
    if (tamaActive && !simonGameIsActive() && !stopGameIsActive()) {
        // Forward button edges to tamagotchi pre-game tasks
        uint8_t mask = (gButtonPressedLatched[0] ? 0x01 : 0)
                     | (gButtonPressedLatched[1] ? 0x02 : 0)
                     | (gButtonPressedLatched[2] ? 0x04 : 0);
        if (mask) tamaOnButton(mask);
    }

    // ── ⑦ Sleep entry (blocks until wakeup if conditions met) ─────────────
    if (badgeFsmHandleSleepEntry()) return;

    // If tamaOnButton just launched a game this frame, skip the idle render.
    // GAME_TICK will own the display from the next frame onward.
    // Without this guard, eyesDrawBoth (sick mode) would overwrite the game's
    // first drawAllUi call, causing a one-frame sick-eye flash at game launch.
    if (simonGameIsActive() || stopGameIsActive() || snakeGameIsActive()
            || mastermindGameIsActive() || tetrisGameIsActive()
            || flappyGameIsActive() || breakoutGameIsActive() || pacmanGameIsActive()
            || doodleGameIsActive() || mazeGameIsActive()
            || dinoGameIsActive() || spaceGameIsActive()) {
        waitNextFrame();
        return;
    }

    // ── ⑧ Idle frame ───────────────────────────────────────────────────────
    // While the FSM is in Sleeping stage (BG ON / GATT / OTA preventing deep
    // sleep), keep screens blank — identical to what deep sleep leaves behind.
    // Exception: never blank during a tamagotchi celebration (tamaBusy) even if
    // badgeFsmTick hasn't had a chance to restore Awake yet this frame.
    if (gBadgeMode == BadgeMode::SleepMode && gWakeStage == WakeStage::Sleeping
            && !tamaBusy()) {
        displaysClear();
        displaysOff();
        ledAnimTick(now);
        rtttlTick(now);
        cryTick(now);
        otaTick();
        waitNextFrame();
        return;
    }

    displaysOn();

    EyePose       pose  = badgeFsmComputePose(now);
    EyeExpression expr  = badgeFsmComputeExpression(now);
    const char*   text  = badgeFsmScrollText(now);

    eyesDrawBoth(pose, expr, text);
    ledAnimTick(now);
    rtttlTick(now);
    cryTick(now);

    otaTick();

    waitNextFrame();
}

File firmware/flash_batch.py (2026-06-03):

#!/usr/bin/env python3
"""
Sthack 2026 Badge Flasher — Batch / Auto flash tool

Modes:
  (default)  Batch: press Enter to scan + flash all connected badges.
  --auto     Auto:  monitor serial ports and flash as soon as a badge
             sends "waiting for download".

Options:
  --audio    Announce the badge number via TTS when each flash completes.
"""

import argparse
import subprocess
import threading
import time
import re
import sys
from pathlib import Path
from dataclasses import dataclass
from typing import Optional
from enum import Enum

# Auto-install dependencies
try:
    import serial
    from rich.console import Console
    from rich.live import Live
    from rich.table import Table
    from rich.text import Text
    from rich.panel import Panel
    from rich import box
    from serial.tools import list_ports
except ImportError:
    print("Installing dependencies...")
    subprocess.run([sys.executable, "-m", "pip", "install", "rich", "pyserial"], check=True)
    import serial
    from rich.console import Console
    from rich.live import Live
    from rich.table import Table
    from rich.text import Text
    from rich.panel import Panel
    from rich import box
    from serial.tools import list_ports

console = Console()

PROJECT_DIR = Path(__file__).parent / "badge_v2"
ENV         = "esp32dev"

ESP32_KEYWORDS = ["CP210", "CH340", "CH341", "FTDI", "SILABS", "USB SERIAL", "USB-SERIAL", "UART"]
ESP32_VIDS     = {0x10C4, 0x1A86, 0x0403, 0x067B, 0x239A}

AUTO_TRIGGER = "waiting for download"

# ── Badge numbering (thread-safe, shared across all flash threads) ─────────────
_badge_counter      = 0
_badge_counter_lock = threading.Lock()

def _assign_number(device: "Device") -> int:
    """Assign the next sequential badge number to a device (first flash only)."""
    global _badge_counter
    with _badge_counter_lock:
        _badge_counter += 1
        device.badge_number = _badge_counter
        return _badge_counter

# ── TTS ───────────────────────────────────────────────────────────────────────
_audio_enabled = False

def _beep():
    """Non-blocking beep using an existing system sound file (no temp file creation)."""
    try:
        if sys.platform == "darwin":
            subprocess.Popen(
                ["afplay", "/System/Library/Sounds/Tink.aiff"],
                stdout=subprocess.DEVNULL, stderr=subprocess.DEVNULL,
            )
        else:
            subprocess.Popen(
                ["paplay", "/usr/share/sounds/freedesktop/stereo/bell.oga"],
                stdout=subprocess.DEVNULL, stderr=subprocess.DEVNULL,
            )
    except Exception:
        pass


def _speak(text: str):
    """Non-blocking TTS announcement (macOS: say, Linux: espeak)."""
    if not _audio_enabled:
        return
    try:
        cmd = ["say", text] if sys.platform == "darwin" else ["espeak", text]
        subprocess.Popen(cmd, stdout=subprocess.DEVNULL, stderr=subprocess.DEVNULL)
    except FileNotFoundError:
        pass


# ── Data model ────────────────────────────────────────────────────────────────

class Status(Enum):
    WAITING    = "waiting"
    MONITORING = "monitoring"   # auto mode: serial open, watching
    READY      = "ready"        # auto mode: trigger detected, about to flash
    FLASHING   = "flashing"
    SUCCESS    = "success"
    FAILED     = "failed"


@dataclass
class Device:
    port:         str
    name:         str
    status:       Status        = Status.WAITING
    progress:     int           = 0
    message:      str           = ""
    start_time:   Optional[float] = None
    end_time:     Optional[float] = None
    flash_count:  int           = 0
    badge_number: Optional[int] = None   # assigned on first successful flash


# ── Device detection ──────────────────────────────────────────────────────────

def detect_devices() -> list[Device]:
    devices = []
    seen: set[str] = set()
    for p in sorted(list_ports.comports(), key=lambda x: x.device):
        desc = (p.description or "").upper()
        vid  = p.vid or 0
        is_esp = any(kw in desc for kw in ESP32_KEYWORDS) or vid in ESP32_VIDS
        if sys.platform == "darwin" and p.device.startswith("/dev/tty."):
            continue
        if not is_esp:
            continue
        key = p.location or f"{p.vid}:{p.pid}:{p.serial_number}"
        if key in seen:
            continue
        seen.add(key)
        devices.append(Device(port=p.device, name=(p.description or p.device)[:40]))
    return devices


# ── Rendering ─────────────────────────────────────────────────────────────────

def _bar(progress: int, width: int = 20) -> str:
    filled = int(progress / 100 * width)
    return f"[{'█' * filled}{'░' * (width - filled)}]"


def _elapsed(device: Device) -> str:
    if not device.start_time:
        return "—"
    end = device.end_time or time.time()
    return f"{end - device.start_time:.1f}s"
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
